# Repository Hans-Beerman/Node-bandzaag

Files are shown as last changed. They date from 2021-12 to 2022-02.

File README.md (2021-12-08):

**NodeStandard**

Node bandzaag is based on the standard node, and is used at the MakerSpace Leiden, to control the bandzaag. This repository has the following subdirs:

- **Drawings:**

Schematic of the wiring between the different modules used

- **KiCad\_files:**

The design of the PCB for the Node/Controller. De PCB in this design is not meant to be used for a real PCB. It is used as guideline for a handmade PCB

- **Photos:**

Some photos of the Node made.

- **PlatformIO\_Files:**

The source code for the Node and the display used. For the development of this software PlatformIO is used. PlatformIO is an Extension on Visual Studio Code.

Currently some of the directories are empty, because the node is not ready yet.

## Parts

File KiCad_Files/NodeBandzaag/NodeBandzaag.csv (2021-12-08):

Source: | /root/Projects/NodeBandzaag/KiCad_Files/NodeBandzaag/NodeBandzaag.sch
Date: | wo 08 dec 2021 19:24:39 CET
Tool: | Eeschema 5.1.12-84ad8e8a86~92~ubuntu20.04.1
Generator: | /usr/share/kicad/plugins/bom_csv_grouped_by_value.py
Component Count: | 36
Individual Components:
Item | Qty | Reference(s) | Value | LibPart | Footprint | Datasheet | Field4 | Field5
 |  | C1 | 10uF | Device:CP | Capacitor_THT:CP_Radial_D6.3mm_P2.50mm | ~
 |  | C8 | 100uF | Device:CP | Capacitor_THT:CP_Radial_D6.3mm_P2.50mm | ~
 |  | C9 | 2n2 | Device:C | Capacitor_THT:C_Disc_D5.1mm_W3.2mm_P5.00mm | ~
 |  | D1 | 1N4148 | Diode:1N4148 | Diode_THT:D_DO-35_SOD27_P7.62mm_Horizontal | https://assets.nexperia.com/documents/data-sheet/1N4148_1N4448.pdf
 |  | D2 | 1N4148 | Diode:1N4148 | Diode_THT:D_DO-35_SOD27_P7.62mm_Horizontal | https://assets.nexperia.com/documents/data-sheet/1N4148_1N4448.pdf
 |  | D3 | LED | Device:LED | LED_THT:LED_D3.0mm | ~
 |  | D5 | 1N4004 | Diode:1N4004 | Diode_THT:D_DO-41_SOD81_P10.16mm_Horizontal | http://www.vishay.com/docs/88503/1n4001.pdf
 |  | J1 | AC Current In | Connector:Screw_Terminal_01x02 | Connector_Phoenix_MSTB:PhoenixContact_MSTB_2,5_2-GF-5,08_1x02_P5.08mm_Horizontal_ThreadedFlange | ~
 |  | J2 | Current coil in | Connector:AudioJack3_SwitchTR | Jack_3.5mm_CUI_FEMPM_Horizontal | ~
 |  | J3 | AC Current loop | Connector:Screw_Terminal_01x02 | TerminalBlock_Phoenix:TerminalBlock_Phoenix_MKDS-1,5-2-5.08_1x02_P5.08mm_Horizontal | ~
 |  | J4 | EXT1 | Connector_Generic:Conn_01x10 | Connector_PinSocket_2.54mm:PinSocket_1x10_P2.54mm_Vertical | ~
 |  | J6 | RFIDReader | Connector:Screw_Terminal_01x04 | TerminalBlock_Phoenix:TerminalBlock_Phoenix_MPT-0,5-4-2.54_1x04_P2.54mm_Horizontal | ~
 |  | J7 | EXT2 | Connector_Generic:Conn_01x10 | Connector_PinSocket_2.54mm:PinSocket_1x10_P2.54mm_Vertical | ~
 |  | J8 | Force output Relay 1 on | Connector_Generic:Conn_01x02 | Connector_PinHeader_2.54mm:PinHeader_1x02_P2.54mm_Vertical | ~
 |  | J10 | Opto Coupler 1 in | Connector:Screw_Terminal_01x02 | Connector_Phoenix_MSTB:PhoenixContact_MSTB_2,5_2-GF-5,08_1x02_P5.08mm_Horizontal_ThreadedFlange | ~
 |  | J13 | Relay 1 Output | Connector:Screw_Terminal_01x03 | Connector_Phoenix_MSTB:PhoenixContact_MSTB_2,5_3-GF-5,08_1x03_P5.08mm_Horizontal_ThreadedFlange | ~
 |  | J29 | Current sensor select | Connector_Generic:Conn_01x03 | Connector_PinHeader_2.54mm:PinHeader_1x03_P2.54mm_Vertical | ~
 |  | JP1 | 230VAC-N | Jumper:SolderJumper_2_Open | Footprints:SolderJumper-2_P3mm_Open_RoundedPad | ~
 |  | JP4 | 230VAC-L | Jumper:SolderJumper_2_Open | Footprints:SolderJumper-2_P3mm_Open_RoundedPad | ~
 |  | K1 | SANYOU_SRD_Form_C | Relay:SANYOU_SRD_Form_C | Relay_THT:Relay_SPDT_SANYOU_SRD_Series_Form_C | http://www.sanyourelay.ca/public/products/pdf/SRD.pdf
 |  | L1 | TA12 | ZMCT118F:ZMCT118F | Footprints:TA12-100 | ~
 |  | OK1 | PC814 | PC814:PC814 | Package_DIP:DIP-4_W7.62mm |  | unknown | 9707662
 |  | Q1 | BC547 | Transistor_BJT:BC547 | Package_TO_SOT_THT:TO-92_Inline | http://www.fairchildsemi.com/ds/BC/BC547.pdf
 |  | Q6 | 2N3906 | Transistor_BJT:2N3906 | Package_TO_SOT_THT:TO-92_Inline | https://www.onsemi.com/pub/Collateral/2N3906-D.PDF
 |  | R1 | 33 | Device:R | Resistor_THT:R_Axial_DIN0207_L6.3mm_D2.5mm_P7.62mm_Horizontal | ~
 |  | R2 | 4k7 | Device:R | Resistor_THT:R_Axial_DIN0207_L6.3mm_D2.5mm_P7.62mm_Horizontal | ~
 |  | R3 | 2k2 | Device:R | Resistor_THT:R_Axial_DIN0207_L6.3mm_D2.5mm_P7.62mm_Horizontal | ~
 |  | R4 | 4k7 | Device:R | Resistor_THT:R_Axial_DIN0207_L6.3mm_D2.5mm_P7.62mm_Horizontal | ~
 |  | R5 | 22k | Device:R | Resistor_THT:R_Axial_DIN0207_L6.3mm_D2.5mm_P7.62mm_Horizontal | ~
 |  | R6 | 22k | Device:R | Resistor_THT:R_Axial_DIN0207_L6.3mm_D2.5mm_P7.62mm_Horizontal | ~
 |  | R9 | 1k | Device:R | Resistor_THT:R_Axial_DIN0207_L6.3mm_D2.5mm_P7.62mm_Horizontal | ~
 |  | R11 | 2k2 | Device:R | Resistor_THT:R_Axial_DIN0207_L6.3mm_D2.5mm_P7.62mm_Horizontal | ~
 |  | R13 | 220k | Device:R | Resistor_THT:R_Axial_DIN0516_L15.5mm_D5.0mm_P20.32mm_Horizontal | ~
 |  | R14 | 220k | Device:R | Resistor_THT:R_Axial_DIN0516_L15.5mm_D5.0mm_P20.32mm_Horizontal | ~
 |  | R30 | 1k | Device:R | Resistor_THT:R_Axial_DIN0207_L6.3mm_D2.5mm_P7.62mm_Horizontal | ~
 |  | U1 | MCP23017_SP | Interface_Expansion:MCP23017_SP | Package_DIP:DIP-28_W7.62mm | http://ww1.microchip.com/downloads/en/DeviceDoc/20001952C.pdf
Collated Components:
Item | Qty | Reference(s) | Value | LibPart | Footprint | Datasheet | Field4 | Field5
1 | 1 | C1 | 10uF | Device:CP | Capacitor_THT:CP_Radial_D6.3mm_P2.50mm | ~
2 | 1 | C8 | 100uF | Device:CP | Capacitor_THT:CP_Radial_D6.3mm_P2.50mm | ~
3 | 1 | C9 | 2n2 | Device:C | Capacitor_THT:C_Disc_D5.1mm_W3.2mm_P5.00mm | ~
4 | 2 | D1, D2 | 1N4148 | Diode:1N4148 | Diode_THT:D_DO-35_SOD27_P7.62mm_Horizontal | https://assets.nexperia.com/documents/data-sheet/1N4148_1N4448.pdf
5 | 1 | D3 | LED | Device:LED | LED_THT:LED_D3.0mm | ~
6 | 1 | D5 | 1N4004 | Diode:1N4004 | Diode_THT:D_DO-41_SOD81_P10.16mm_Horizontal | http://www.vishay.com/docs/88503/1n4001.pdf
7 | 1 | J1 | AC Current In | Connector:Screw_Terminal_01x02 | Connector_Phoenix_MSTB:PhoenixContact_MSTB_2,5_2-GF-5,08_1x02_P5.08mm_Horizontal_ThreadedFlange | ~
8 | 1 | J2 | Current coil in | Connector:AudioJack3_SwitchTR | Jack_3.5mm_CUI_FEMPM_Horizontal | ~
9 | 1 | J3 | AC Current loop | Connector:Screw_Terminal_01x02 | TerminalBlock_Phoenix:TerminalBlock_Phoenix_MKDS-1,5-2-5.08_1x02_P5.08mm_Horizontal | ~
10 | 1 | J4 | EXT1 | Connector_Generic:Conn_01x10 | Connector_PinSocket_2.54mm:PinSocket_1x10_P2.54mm_Vertical | ~
11 | 1 | J6 | RFIDReader | Connector:Screw_Terminal_01x04 | TerminalBlock_Phoenix:TerminalBlock_Phoenix_MPT-0,5-4-2.54_1x04_P2.54mm_Horizontal | ~
12 | 1 | J7 | EXT2 | Connector_Generic:Conn_01x10 | Connector_PinSocket_2.54mm:PinSocket_1x10_P2.54mm_Vertical | ~
13 | 1 | J8 | Force output Relay 1 on | Connector_Generic:Conn_01x02 | Connector_PinHeader_2.54mm:PinHeader_1x02_P2.54mm_Vertical | ~
14 | 1 | J10 | Opto Coupler 1 in | Connector:Screw_Terminal_01x02 | Connector_Phoenix_MSTB:PhoenixContact_MSTB_2,5_2-GF-5,08_1x02_P5.08mm_Horizontal_ThreadedFlange | ~
15 | 1 | J13 | Relay 1 Output | Connector:Screw_Terminal_01x03 | Connector_Phoenix_MSTB:PhoenixContact_MSTB_2,5_3-GF-5,08_1x03_P5.08mm_Horizontal_ThreadedFlange | ~
16 | 1 | J29 | Current sensor select | Connector_Generic:Conn_01x03 | Connector_PinHeader_2.54mm:PinHeader_1x03_P2.54mm_Vertical | ~
17 | 1 | JP1 | 230VAC-N | Jumper:SolderJumper_2_Open | Footprints:SolderJumper-2_P3mm_Open_RoundedPad | ~
18 | 1 | JP4 | 230VAC-L | Jumper:SolderJumper_2_Open | Footprints:SolderJumper-2_P3mm_Open_RoundedPad | ~
19 | 1 | K1 | SANYOU_SRD_Form_C | Relay:SANYOU_SRD_Form_C | Relay_THT:Relay_SPDT_SANYOU_SRD_Series_Form_C | http://www.sanyourelay.ca/public/products/pdf/SRD.pdf
20 | 1 | L1 | TA12 | ZMCT118F:ZMCT118F | Footprints:TA12-100 | ~
21 | 1 | OK1 | PC814 | PC814:PC814 | Package_DIP:DIP-4_W7.62mm |  | unknown | 9707662
22 | 1 | Q1 | BC547 | Transistor_BJT:BC547 | Package_TO_SOT_THT:TO-92_Inline | http://www.fairchildsemi.com/ds/BC/BC547.pdf
23 | 1 | Q6 | 2N3906 | Transistor_BJT:2N3906 | Package_TO_SOT_THT:TO-92_Inline | https://www.onsemi.com/pub/Collateral/2N3906-D.PDF
24 | 1 | R1 | 33 | Device:R | Resistor_THT:R_Axial_DIN0207_L6.3mm_D2.5mm_P7.62mm_Horizontal | ~
25 | 2 | R2, R4 | 4k7 | Device:R | Resistor_THT:R_Axial_DIN0207_L6.3mm_D2.5mm_P7.62mm_Horizontal | ~
26 | 2 | R3, R11 | 2k2 | Device:R | Resistor_THT:R_Axial_DIN0207_L6.3mm_D2.5mm_P7.62mm_Horizontal | ~
27 | 2 | R5, R6 | 22k | Device:R | Resistor_THT:R_Axial_DIN0207_L6.3mm_D2.5mm_P7.62mm_Horizontal | ~
28 | 2 | R9, R30 | 1k | Device:R | Resistor_THT:R_Axial_DIN0207_L6.3mm_D2.5mm_P7.62mm_Horizontal | ~
29 | 2 | R13, R14 | 220k | Device:R | Resistor_THT:R_Axial_DIN0516_L15.5mm_D5.0mm_P20.32mm_Horizontal | ~
30 | 1 | U1 | MCP23017_SP | Interface_Expansion:MCP23017_SP | Package_DIP:DIP-28_W7.62mm | http://ww1.microchip.com/downloads/en/DeviceDoc/20001952C.pdf

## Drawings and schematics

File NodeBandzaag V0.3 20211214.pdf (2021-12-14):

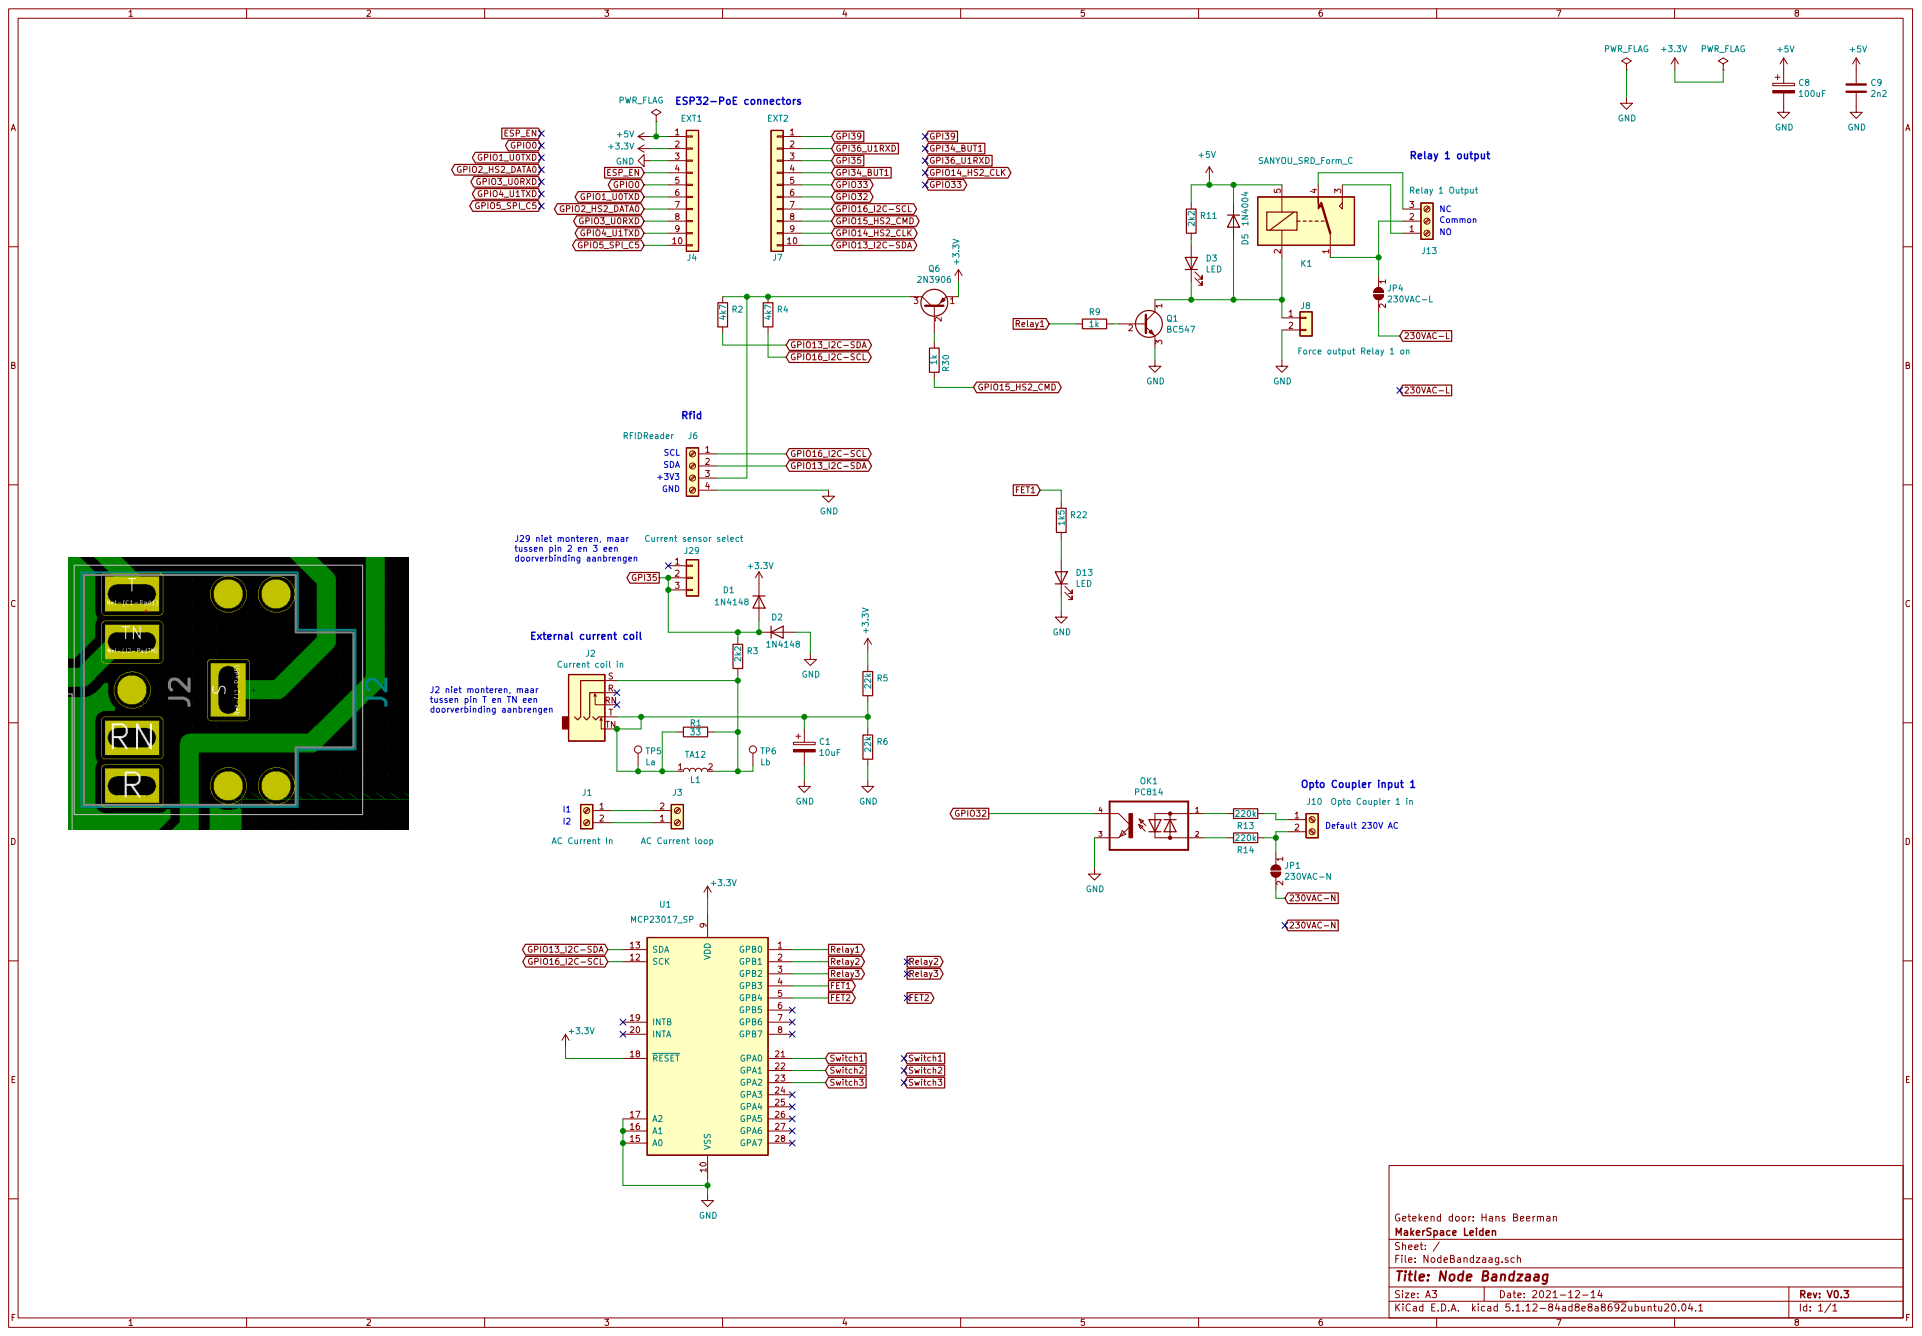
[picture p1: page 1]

Common Default 230V AC
NO Opto Coupler input 1

J29 niet monteren, maar
tussen pin 2 en 3 een
doorverbinding aanbrengen

J2 niet monteren, maar
tussen pin T en TN een

File: NodeBandzaag.sch Sheet: / MakerSpace Leiden Getekend door: Hans Beerman

Id: 1/1 Title: Node Bandzaag

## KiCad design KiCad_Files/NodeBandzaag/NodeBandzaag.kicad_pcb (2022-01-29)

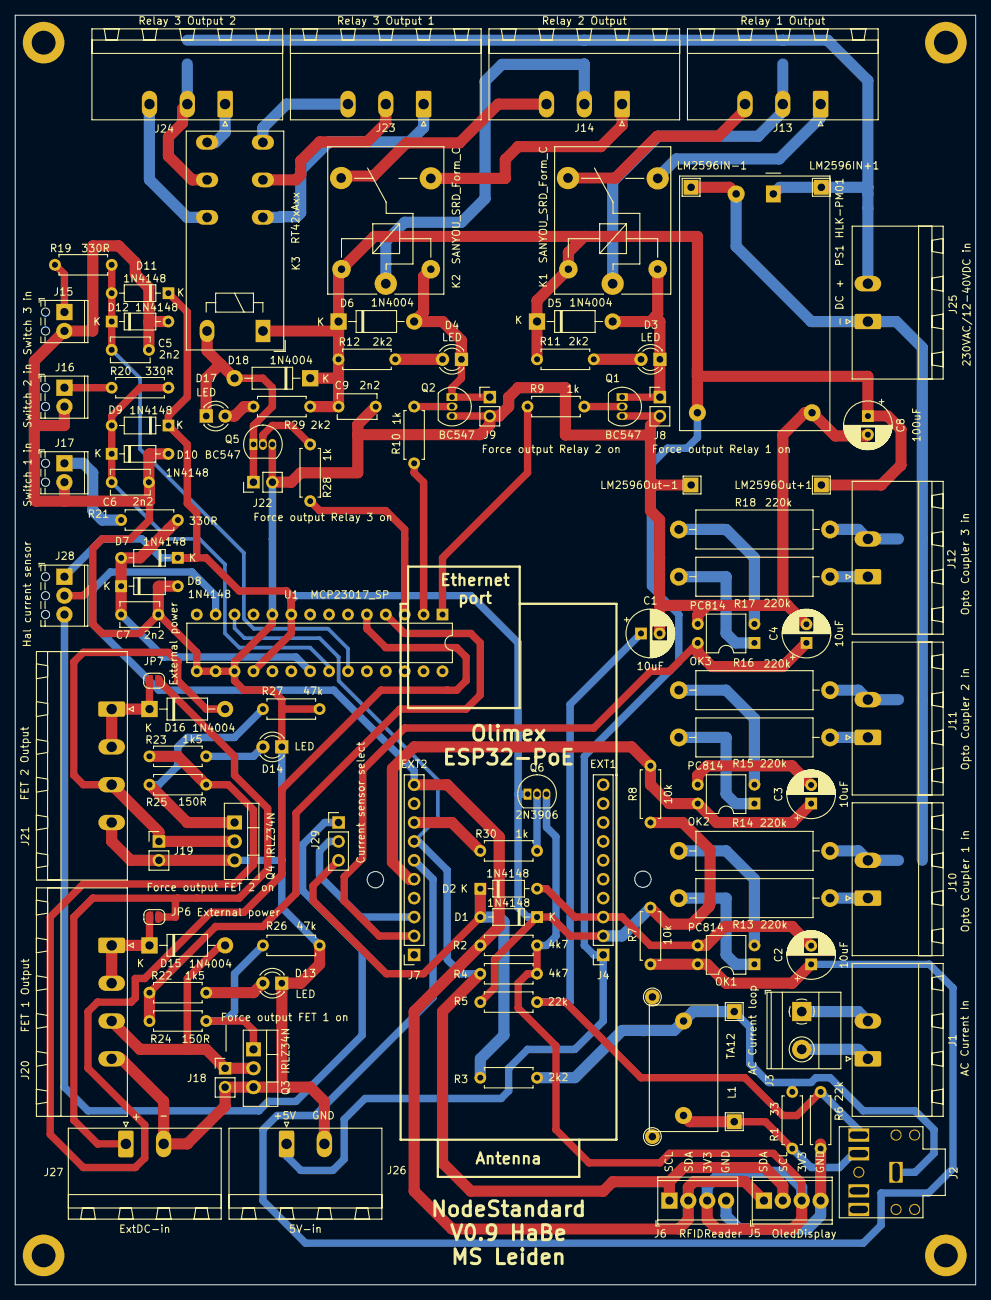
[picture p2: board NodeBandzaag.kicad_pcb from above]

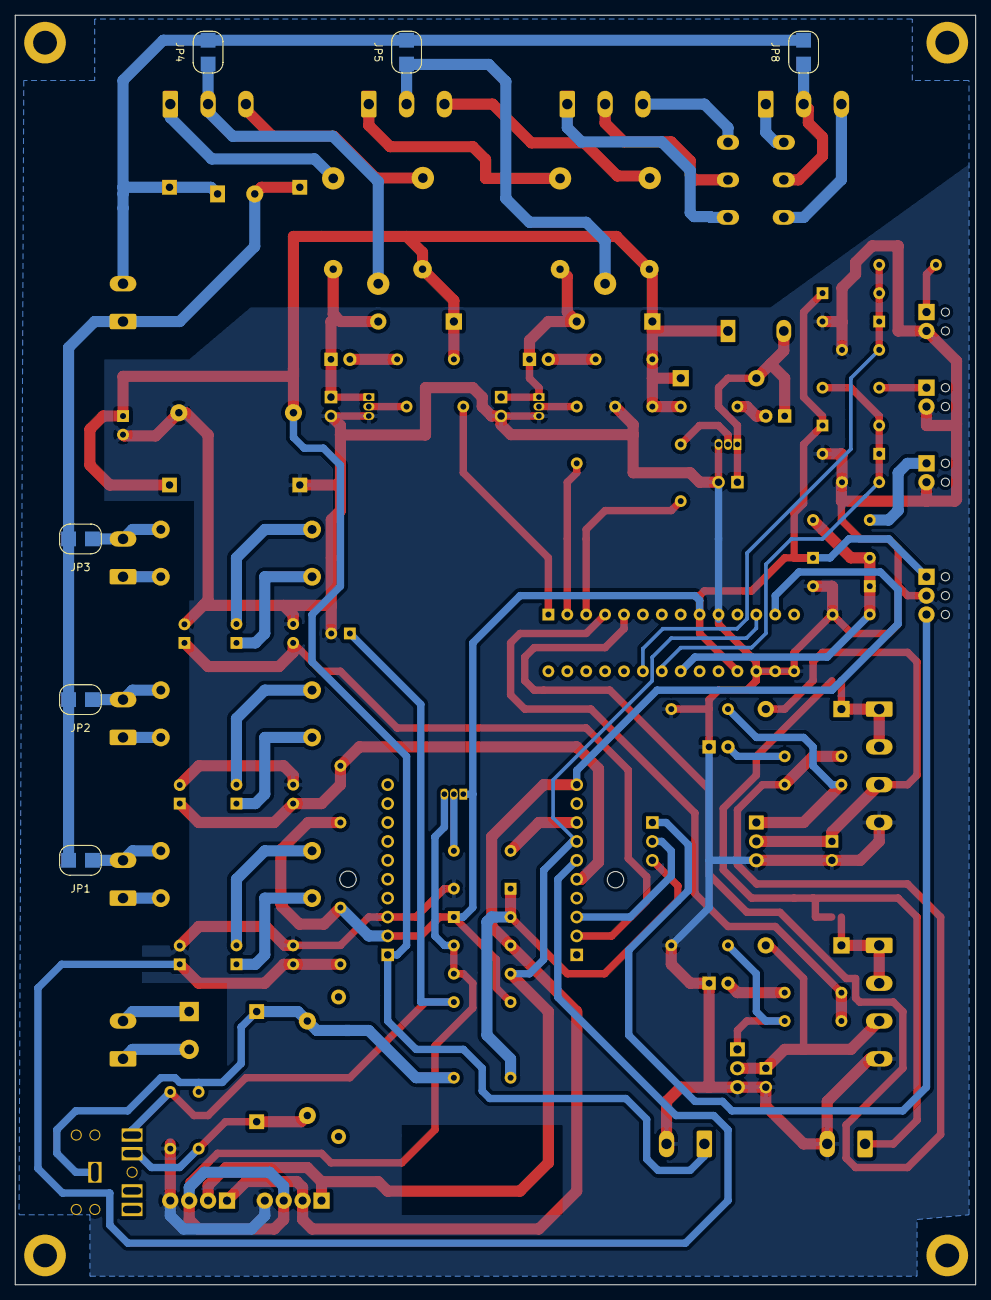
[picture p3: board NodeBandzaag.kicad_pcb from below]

Board: 2 copper layers, 129.0 x 170.6 mm, 115 parts (6 on the bottom side), 74 nets.

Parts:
C1, C2, C3, C4: 10uF; CP_Radial_D6.3mm_P2.50mm
C5, C6, C7, C9: 2n2; C_Disc_D5.1mm_W3.2mm_P5.00mm
C8: 100uF; CP_Radial_D6.3mm_P2.50mm
D1, D2, D7, D8, D9, D10, D11, D12: 1N4148; D_DO-35_SOD27_P7.62mm_Horizontal
D3, D4, D13, D14, D17: LED; LED_D3.0mm
D5, D6, D15, D16, D18: 1N4004; D_DO-41_SOD81_P10.16mm_Horizontal
J1: AC Current In; PhoenixContact_MSTB_2,5_2-GF-5,08_1x02_P5.08mm_Horizontal_T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
J2: Current coil in; Jack_3.5mm_CUI_FEMPM_Horizontal
J3: AC Current loop; TerminalBlock_Phoenix_MKDS-1,5-2-5.08_1x02_P5.08mm_Horizont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
J4: EXT1; PinSocket_1x10_P2.54mm_Vertical
J5: OledDisplay; TerminalBlock_Phoenix_MPT-0,5-4-2.54_1x04_P2.54mm_Horizontal
J6: RFIDReader; TerminalBlock_Phoenix_MPT-0,5-4-2.54_1x04_P2.54mm_Horizontal
J7: EXT2; PinSocket_1x10_P2.54mm_Vertical
J8: Force output Relay 1 on; PinHeader_1x02_P2.54mm_Vertical
J9: Force output Relay 2 on; PinHeader_1x02_P2.54mm_Vertical
J10: Opto Coupler 1 in; PhoenixContact_MSTB_2,5_2-GF-5,08_1x02_P5.08mm_Horizontal_T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
J11: Opto Coupler 2 in; PhoenixContact_MSTB_2,5_2-GF-5,08_1x02_P5.08mm_Horizontal_T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
J12: Opto Coupler 3 in; PhoenixContact_MSTB_2,5_2-GF-5,08_1x02_P5.08mm_Horizontal_T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
J13: Relay 1 Output; PhoenixContact_MSTB_2,5_3-GF-5,08_1x03_P5.08mm_Horizontal_T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
J14: Relay 2 Output; PhoenixContact_MSTB_2,5_3-GF-5,08_1x03_P5.08mm_Horizontal_T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
J15: Switch 3 in; TerminalBlock_Phoenix_MPT-0,5-2-2.54_1x02_P2.54mm_Horizontal
J16: Switch 2 in; TerminalBlock_Phoenix_MPT-0,5-2-2.54_1x02_P2.54mm_Horizontal
J17: Switch 1 in; TerminalBlock_Phoenix_MPT-0,5-2-2.54_1x02_P2.54mm_Horizontal
J18: Force output FET 1 on; PinHeader_1x02_P2.54mm_Vertical
J19: Force output FET 2 on; PinHeader_1x02_P2.54mm_Vertical
J20: FET 1 Output; PhoenixContact_MSTB_2,5_4-GF-5,08_1x04_P5.08mm_Horizontal_T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
J21: FET 2 Output; PhoenixContact_MSTB_2,5_4-GF-5,08_1x04_P5.08mm_Horizontal_T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
J22: Force output Relay 3 on; PinHeader_1x02_P2.54mm_Vertical
J23: Relay 3 Output 1; PhoenixContact_MSTB_2,5_3-GF-5,08_1x03_P5.08mm_Horizontal_T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
J24: Relay 3 Output 2; PhoenixContact_MSTB_2,5_3-GF-5,08_1x03_P5.08mm_Horizontal_T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
J25: 230VAC/12-40VDC in; PhoenixContact_MSTB_2,5_2-GF-5,08_1x02_P5.08mm_Horizontal_T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
J26: 5V-in; PhoenixContact_MSTB_2,5_2-GF-5,08_1x02_P5.08mm_Horizontal_T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
J27: ExtDC-in; PhoenixContact_MSTB_2,5_2-GF-5,08_1x02_P5.08mm_Horizontal_T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
J28: Hal current sensor; TerminalBlock_Phoenix_MPT-0,5-3-2.54_1x03_P2.54mm_Horizontal
J29: Current sensor select; PinHeader_1x03_P2.54mm_Vertical
JP1, JP2, JP3: 230VAC-N; SolderJumper-2_P3mm_Open_RoundedPad
JP4, JP5, JP8: 230VAC-L; SolderJumper-2_P3mm_Open_RoundedPad
JP6, JP7: External power; SolderJumper-2_P1.3mm_Open_RoundedPad1.0x1.5mm
K1, K2: SANYOU_SRD_Form_C; Relay_SPDT_SANYOU_SRD_Series_Form_C
K3: RT42xAxx; Relay_DPDT_Schrack-RT2-FormC_RM5mm
L1: TA12; TA12-100
LM2596IN+1: IN+; TestPoint_THTPad_2.0x2.0mm_Drill1.0mm
LM2596IN-1: IN-; TestPoint_THTPad_2.0x2.0mm_Drill1.0mm
LM2596Out+1: Out+; TestPoint_THTPad_2.0x2.0mm_Drill1.0mm
LM2596Out-1: OUT-; TestPoint_THTPad_2.0x2.0mm_Drill1.0mm
OK1, OK2, OK3: PC814; DIP-4_W7.62mm
PS1: HLK-PM01; Converter_ACDC_HiLink_HLK-PMxx
Q1, Q2, Q5: BC547; TO-92_Inline
Q3, Q4: IRLZ34N; TO-220-3_Vertical
Q6: 2N3906; TO-92_Inline
R1: 33; R_Axial_DIN0207_L6.3mm_D2.5mm_P7.62mm_Horizontal
R2, R4: 4k7; R_Axial_DIN0207_L6.3mm_D2.5mm_P7.62mm_Horizontal
R3, R11, R12, R29: 2k2; R_Axial_DIN0207_L6.3mm_D2.5mm_P7.62mm_Horizontal
R5, R6: 22k; R_Axial_DIN0207_L6.3mm_D2.5mm_P7.62mm_Horizontal
R7, R8: 10k; R_Axial_DIN0207_L6.3mm_D2.5mm_P7.62mm_Horizontal
R9, R10, R28, R30: 1k; R_Axial_DIN0207_L6.3mm_D2.5mm_P7.62mm_Horizontal
R13, R14, R15, R16, R17, R18: 220k; R_Axial_DIN0516_L15.5mm_D5.0mm_P20.32mm_Horizontal
R19, R20, R21: 330R; R_Axial_DIN0207_L6.3mm_D2.5mm_P7.62mm_Horizontal
R22, R23: 1k5; R_Axial_DIN0207_L6.3mm_D2.5mm_P7.62mm_Horizontal
R24, R25: 150R; R_Axial_DIN0207_L6.3mm_D2.5mm_P7.62mm_Horizontal
R26, R27: 47k; R_Axial_DIN0207_L6.3mm_D2.5mm_P7.62mm_Horizontal
TP5: La; TestPoint_THTPad_2.0x2.0mm_Drill1.0mm
TP6: Lb; TestPoint_THTPad_2.0x2.0mm_Drill1.0mm
U1: MCP23017_SP; DIP-28_W7.62mm

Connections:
230VAC-L: J25.2, JP4.2, JP5.2, JP8.2, LM2596IN+1.1, PS1.1
230VAC-N: J25.1, JP1.2, JP2.2, JP3.2, LM2596IN-1.1, PS1.2
+3V3: D1.1, D7.1, D9.1, D11.1, J4.2, J28.1, Q6.1, R5.1, R7.1, R8.1, U1.9, U1.18
+5V: C8.1, C9.1, D5.1, D6.1, D18.1, J4.1, J26.1, K1.5, K2.5, K3.A1, LM2596Out+1.1, PS1.4, R11.1, R12.1, R29.1
ExternalDCPower: J27.1, JP6.1, JP7.1
FET1: R22.1, R24.2, U1.4
FET2: R23.1, R25.2, U1.5
GND: C1.2, C2.2, C3.2, C4.2, C5.2, C6.2, C7.2, C8.2, C9.2, D2.2, D8.2, D10.2, D12.2, D13.1, D14.1, J4.3, J5.4, J6.4, J8.2, J9.2, J15.2, J16.2, J17.2, J18.2, J19.2, J20.4, J21.4, J22.2, J26.2, J27.2, J28.2, LM2596Out-1.1, OK1.3, OK2.3, OK3.3, PS1.3, Q1.3, Q2.3, Q3.3, Q4.3, Q5.3, R6.2, R26.2, R27.2, U1.10, U1.15, U1.16, U1.17
GPI35: J7.3, J29.2
GPI36_U1RXD: C4.1, J7.2, OK3.4
GPIO13_I2C-SDA: J5.1, J6.2, J7.10, R2.2, U1.13
GPIO15_HS2_CMD: J7.8, R30.1
GPIO16_I2C-SCL: J5.2, J6.1, J7.7, R4.2, U1.12
GPIO32: C2.1, J7.6, OK1.4, R7.2
GPIO33: C3.1, J7.5, OK2.4, R8.2
unnamed: C1.1, J2.T, R5.2, R6.1
unnamed: D1.2, D2.1, J29.3, R3.1
unnamed: D3.1, D5.2, J8.1, K1.2, Q1.1
unnamed: D3.2, R11.2
unnamed: D4.1, D6.2, J9.1, K2.2, Q2.1
unnamed: D4.2, R12.2
unnamed: D13.2, R22.2
unnamed: D14.2, R23.2
unnamed: D15.1, J20.1, J20.2, JP6.2
unnamed: D15.2, J18.1, J20.3, Q3.2
unnamed: D16.1, J21.1, J21.2, JP7.2
unnamed: D16.2, J19.1, J21.3, Q4.2
unnamed: D17.1, D18.2, J22.1, K3.A2, Q5.1
unnamed: D17.2, R29.2
unnamed: J1.1, J3.2
unnamed: J1.2, J3.1
unnamed: J2.S, L1.2, R1.1, R3.2, TP6.1
unnamed: J2.TN, L1.1, R1.2, TP5.1
unnamed: J5.3, J6.3, Q6.3, R2.1, R4.1
unnamed: J10.1, R13.1
unnamed: J10.2, JP1.1, R14.1
unnamed: J11.1, R15.1
unnamed: J11.2, JP2.1, R16.1
unnamed: J12.1, R17.1
unnamed: J12.2, JP3.1, R18.1
unnamed: J13.1, K1.3
unnamed: J13.2, JP4.1, K1.1
unnamed: J13.3, K1.4
unnamed: J14.1, K2.3
unnamed: J14.2, JP5.1, K2.1
unnamed: J14.3, K2.4
unnamed: J15.1, R19.1
unnamed: J16.1, R20.1
unnamed: J17.1, R21.1
unnamed: J23.1, K3.12
unnamed: J23.2, K3.11
unnamed: J23.3, K3.14
unnamed: J24.1, K3.24
unnamed: J24.2, JP8.1, K3.21
unnamed: J24.3, K3.22
unnamed: J28.3, J29.1
unnamed: OK1.1, R13.2
unnamed: OK1.2, R14.2
unnamed: OK2.1, R15.2
unnamed: OK2.2, R16.2
unnamed: OK3.1, R17.2
unnamed: OK3.2, R18.2
unnamed: Q1.2, R9.1
unnamed: Q2.2, R10.1
unnamed: Q3.1, R24.1, R26.1
unnamed: Q4.1, R25.1, R27.1
unnamed: Q5.2, R28.1
unnamed: Q6.2, R30.2
Relay1: R9.2, U1.1
Relay2: R10.2, U1.2
Relay3: R28.2, U1.3
Switch1: C7.1, D7.2, D8.1, R21.2, U1.21
Switch2: C6.1, D9.2, D10.1, R20.2, U1.22
Switch3: C5.1, D11.2, D12.1, R19.2, U1.23

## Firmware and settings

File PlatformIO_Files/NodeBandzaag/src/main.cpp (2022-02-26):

/*
   Copyright 2015-2018 Dirk-Willem van Gulik <dirkx@webweaving.org>
   Copyright 2020-2021 Hans Beerman <hans.beerman@xs4all.nl>
                       Stichting Makerspace Leiden, the Netherlands.

   Licensed under the Apache License, Version 2.0 (the "License");
   you may not use this file except in compliance with the License.
   You may obtain a copy of the License at

       http://www.apache.org/licenses/LICENSE-2.0

   Unless required by applicable law or agreed to in writing, software
   distributed under the License is distributed on an "AS IS" BASIS,
   WITHOUT WARRANTIES OR CONDITIONS OF ANY KIND, either express or implied.
   See the License for the specific language governing permissions and
   limitations under the License.
*/

#ifndef ESP32
#error "The Node lintzaag uses an ESP32 based board (Olimex ESP32-PoE)!"
#endif

// An Olimex ESP32-PoE is used (default is POESP board (Aart board))
#define ESP32_PoE


// for debugging
// see DEBUGIT flag in platformio.ini

// i2C params
// Defined in platformio.ini:
// RFID_SDA_PIN=13
// RFID_SCL_PIN=16

#include <Arduino.h>
#include <PowerNodeV11.h>
#include <ACNode.h>
#include <RFID.h>   // NFC version
#include <SIG2.h>
#include <Cache.h>
#include <OptoDebounce.h>
#include <ButtonDebounce.h>
#include <EEPROM.h>
#include <WiFiUdp.h>
#include <NTP.h> // install NTP by Stefan Staub
#include <CurrentTransformerWithCallbacks.h>

//
// information about NTP.h, see: https://platformio.org/lib/show/5438/NTP
//

#include "MCP23017IO.h"
#include ".passwd.h"

/* If using WiFi instead of a fixed ethernet connection, and/or OTA:

Change .passwd.h in the /include directoy containing the following information

#pragma once

#define WIFI_NETWORK "YOUR_SSID"
#define WIFI_PASSWD "YOUR_PASSWD"

#define OTA_PASSWD "YOUR_OTA_PASSWD"
// This OTA_PASSWD must be the same as the one in platformio.ini
*/

// software version
#define SOFTWARE_VERSION "  V1.0.5.0 "

#define MACHINE "lintzaag"

// See https://mailman.makerspaceleiden.nl/mailman/private/deelnemers/2019-February/019837.html

// Introduced by alex - 2020-01-8

// Clear EEProm + Cache button
// Press BUT1 on Olimex ESP32 PoE module before (re)boot of node
// keep BUT1 pressed for at least 5 s
// After the release of BUT1 node will restart with empty EEProm and empty cache
#define CLEAR_EEPROM_AND_CACHE_BUTTON           (34)
#define CLEAR_EEPROM_AND_CACHE_BUTTON_PRESSED   (LOW)
#define MAX_WAIT_TIME_BUTTON_PRESSED            (4000)  // in ms

#define MAX_WAIT_FOR_CARD_TIME                  (20) // in s = 20 seconds

// for normal operation
#define MAX_ACTIVE_TIME                         (120) // in minutes = 2 hour
// for test
// #define MAX_ACTIVE_TIME                         (1) // in minutes = 1 minute
// for normal operation
// #define MAX_IDLE_TIME                           (35 * 60 * 1000) // auto power off after 35 minutes of no use.
#define MAX_IDLE_TIME                           (100 * 1000) // auto power off after 100 s of no use.
// for test
// #define MAX_IDLE_TIME                           (1 * 60 * 1000) // auto power off after 1 minute of no use.

#define SWITCH_POWER_OFF_WAITTIME               (3000) // in ms

#define CHECK_NFC_READER_AVAILABLE_TIME_WINDOW  (10000) // in ms  
#define GPIOPORT_I2C_RECOVER_SWITCH             (15)       

#define OPTO_COUPLER_INPUT1                     (32)
#define OPTO_COUPLER_INPUT2                     (33)
#define OPTO_COUPLER_INPUT3                     (36)

#define CURRENT_SAMPLES_PER_SEC                 (500) // one sample each 2 ms
#define CURRENT_THRESHOLD                       (0.07)  // Irms ~ 4A, with current transformer 1:1000 and resistor of 36 ohm

#define BLINK_NOT_CONNECTED                     (1000)	// blink on/of every 1000 ms
#define BLINK_ERROR                             (300) // blink on/of every 300 ms
#define BLINK_CHECKING_RFIDCARD                 (600) // blink on/of every 600 ms

CurrentTransformerWithCallbacks currentSensor = CurrentTransformerWithCallbacks(CURRENT_GPIO, CURRENT_SAMPLES_PER_SEC);

// 230VAC optocoupler
OptoDebounce opto1(OPTO_COUPLER_INPUT1); // wired to the 230VAC of the welding equipment, to detect if it is switched on or not

bool opto1IsOn = false;
bool previousOpto1IsOn = false;
bool opto1Error = false;
bool powerWhileSwitchedOffError = false;
bool switchPowerOff = false;

#ifdef WIFI_NETWORK
ACNode node = ACNode(MACHINE, WIFI_NETWORK, WIFI_PASSWD);
#else
ACNode node = ACNode(MACHINE);
#endif

#define USE_CACHE_FOR_TAGS true
#define USE_NFC_RFID_CARD true

// NTP update window
#define NTP_UPDATE_WINDOW (60000) // in ms

RFID reader = RFID(USE_CACHE_FOR_TAGS, USE_NFC_RFID_CARD); // use tags are stored in cache, to allow access in case the MQTT server is down; also use NFC RFID card

MqttLogStream mqttlogStream = MqttLogStream();
TelnetSerialStream telnetSerialStream = TelnetSerialStream();

#ifdef OTA_PASSWD
OTA ota = OTA(OTA_PASSWD);
#endif

WiFiUDP wifiUDP;
NTP ntp(wifiUDP);

char ntpBootDateTimeStr[64];
unsigned long NTPUpdatedTime = 0;
int previousHour = -1;

char ntpCurrentDateTimeStr[64];
int currentHour;
int currentMinutes;
int currentSecs;
int currentDay;
int currentMonth;
int currentYear;

// LED aartLed = LED(SYSTEM_LED);    // defaults to the aartLed - otherwise specify a GPIO.

typedef enum {
  BOOTING,                  // starting up
  OUTOFORDER,               // device not functional.
  REBOOT,                   // forcefull reboot
  TRANSIENTERROR,           // hopefully goes away level error
  NOCONN,                   // sort of fairly hopless (though we can cache RFIDs!)
  NOTACTIVE,                // waiting for card.
  CHECKINGCARD,
  CLEARSTATUS,
  APPROVED,
  REJECTCARD,
  REJECTED,
  POWERED,
  ACTIVE,                   // running
} machinestates_t;


#define NEVER (0)

struct {
  const char * label;                   // name of this state
  LED::led_state_t ledState;            // flashing pattern for the aartLED. Zie ook https://wiki.makerspaceleiden.nl/mediawiki/index.php/Powernode_1.1.
  time_t maxTimeInMilliSeconds;         // how long we can stay in this state before we timeout.
  machinestates_t failStateOnTimeout;   // what state we transition to on timeout.
  unsigned long timeInState;
  unsigned long timeoutTransitions;
  unsigned long autoReportCycle;
} state[ACTIVE + 1] =
{
  { "Booting",                           LED::LED_ERROR,                      120 * 1000, REBOOT,                       0 },
  { "Module out of order",               LED::LED_ERROR,                      120 * 1000, REBOOT,                       5 * 60 * 1000 },
  { "Rebooting",                         LED::LED_ERROR,                      120 * 1000, REBOOT,                       0 },
  { "Transient Error",                   LED::LED_ERROR,                        5 * 1000, NOTACTIVE,                    5 * 60 * 1000 },
  { "No network",                        LED::LED_FLASH,                           NEVER, NOCONN,                       0 },
  { "Not active",                        LED::LED_IDLE,                            NEVER, NOTACTIVE,                    0 },
  { "Checking card",                     LED::LED_PENDING,                      7 * 1000, REJECTCARD,                   0 },
  { "Clear status",                      LED::LED_PENDING,                         NEVER, NOTACTIVE,                    0 },
  { "Approved card",                     LED::LED_PENDING, MAX_WAIT_FOR_CARD_TIME * 1000, CLEARSTATUS,                  0 },
  { "Reject card",                       LED::LED_ERROR,                        5 * 1000, REJECTED,                     0 },
  { "Rejected",                          LED::LED_ERROR,                        7 * 1000, CLEARSTATUS,                  0 },
  { "Powered - but idle",                LED::LED_ON,                              NEVER, NOTACTIVE,                    0 },
  { "Active (running)",                  LED::LED_ON,        MAX_ACTIVE_TIME * 60 * 1000, CLEARSTATUS,                  0 },
};

unsigned long laststatechange = 0, lastReport = 0;
static machinestates_t laststate = OUTOFORDER;
machinestates_t machinestate = BOOTING;

unsigned long switchPowerOffTime = 0;

// to handle onconnect only once (only after reboot)
static bool firstOnConnectTime = true;

char reportStr[128];

unsigned long approvedCards = 0;
unsigned long rejectedCards = 0;

// For storing the local IP address of the node
IPAddress theLocalIPAddress;

unsigned long lastCheckNFCReaderTime = 0;

bool nodeWasConnected = false;

void checkClearEEPromAndCacheButtonPressed(void) {
  unsigned long ButtonPressedTime;
  unsigned long currentSecs;
  unsigned long prevSecs;
  bool firstTime = true;

  // check CLEAR_EEPROM_AND_CACHE_BUTTON pressed
  pinMode(CLEAR_EEPROM_AND_CACHE_BUTTON, INPUT);
  // check if button is pressed for at least 3 s
  Log.println("Checking if the button is pressed for clearing EEProm and cache");
  ButtonPressedTime = millis();  
  prevSecs = MAX_WAIT_TIME_BUTTON_PRESSED / 1000;
  Log.print(prevSecs);
  Log.print(" s");
  while (digitalRead(CLEAR_EEPROM_AND_CACHE_BUTTON) == CLEAR_EEPROM_AND_CACHE_BUTTON_PRESSED) {
    if ((millis() - ButtonPressedTime) >= MAX_WAIT_TIME_BUTTON_PRESSED) {
      if (firstTime == true) {
        Log.print("\rPlease release button");
        firstTime = false;
      }
    } else {
      currentSecs = (MAX_WAIT_TIME_BUTTON_PRESSED - millis()) / 1000;
      if ((currentSecs != prevSecs) && (currentSecs >= 0)) {
        Log.print("\r");
        Log.print(currentSecs);
        Log.print(" s");
        prevSecs = currentSecs;
      }
    }
  }
  if (millis() - ButtonPressedTime >= MAX_WAIT_TIME_BUTTON_PRESSED) {
    Log.print("\rButton for clearing EEProm and cache was pressed for more than ");
    Log.print(MAX_WAIT_TIME_BUTTON_PRESSED / 1000);
    Log.println(" s, EEProm and Cache will be cleared!");
    // Clear EEPROM
    EEPROM.begin(1024);
    wipe_eeprom();
    Log.println("EEProm cleared!");
    // Clear cache
    prepareCache(true);
    Log.println("Cache cleared!");
    // wait until button is released, than reboot
    while (digitalRead(CLEAR_EEPROM_AND_CACHE_BUTTON) == CLEAR_EEPROM_AND_CACHE_BUTTON_PRESSED) {
    // do nothing here
    }
    Log.println("Node will be restarted");
    // restart node
    ESP.restart();
  } else {
    Log.println("\rButton was not (or not long enough) pressed to clear EEProm and cache");
  }
}

void setup_GPIO() {
  // for recovery switch I2C
  pinMode(GPIOPORT_I2C_RECOVER_SWITCH, OUTPUT);
  digitalWrite(GPIOPORT_I2C_RECOVER_SWITCH, 0);
}

#define CONNECTION_ERROR_INTERVAL_TIME        (1000)
#define CONNECTION_ERROR_TIME                 (100)

bool connectionErrorIsActive = false;
unsigned long connectionErrorTime = 0;

void resetNFCReader() {
  if (USE_NFC_RFID_CARD) {
    pinMode(RFID_SCL_PIN, OUTPUT);
    digitalWrite(RFID_SCL_PIN, 0);
    pinMode(RFID_SDA_PIN, OUTPUT);
    digitalWrite(RFID_SDA_PIN, 0);
    digitalWrite(GPIOPORT_I2C_RECOVER_SWITCH, 1);
    delay(500);
    digitalWrite(GPIOPORT_I2C_RECOVER_SWITCH, 0);
    reader.begin();
  }
}

void checkNFCReaderAvailable(bool onlyShowError) {
  if (USE_NFC_RFID_CARD) {
    if (!reader.CheckPN53xBoardAvailable()) {
      // Error in communuication with RFID reader, try resetting communication
      Serial.println("Error in communication with RFID reader. Resetting communication\r");
      pinMode(RFID_SCL_PIN, OUTPUT);
      digitalWrite(RFID_SCL_PIN, 0);
      pinMode(RFID_SDA_PIN, OUTPUT);
      digitalWrite(RFID_SDA_PIN, 0);
      digitalWrite(GPIOPORT_I2C_RECOVER_SWITCH, 1);
      delay(500);
      digitalWrite(GPIOPORT_I2C_RECOVER_SWITCH, 0);
      reader.begin();
    } else {
      // No error
      if (!onlyShowError) {
        Serial.println("Reader is available!\r");
      }
    }
  }
}

void getCurrentNTPDateTime() {
  currentHour = ntp.hours();
  currentMinutes = ntp.minutes();
  currentSecs = ntp.seconds();
  currentDay = ntp.day();
  currentMonth = ntp.month();
  currentYear = ntp.year();
  snprintf(ntpCurrentDateTimeStr, sizeof(ntpCurrentDateTimeStr), "%4d-%02d-%02d %02d:%02d:%02d", currentYear, currentMonth, currentDay, currentHour, currentMinutes, currentSecs);
}

void initNTP(void) {
  ntp.ruleDST("CEST", Last, Sun, Mar, 2, 120); // last sunday in march 2:00, timezone +120min (+1 GMT + 1h summertime offset)
  ntp.ruleSTD("CET", Last, Sun, Oct, 3, 60); // last sunday in october 3:00, timezone +60min (+1 GMT)
  ntp.begin();
  ntp.update();

  getCurrentNTPDateTime();

  snprintf(ntpBootDateTimeStr, sizeof(ntpBootDateTimeStr), "%s", ntpCurrentDateTimeStr);
}

void setup() {
  Serial.begin(115200);
  Serial.println("\n\n\n");
  Serial.println("Booted: " __FILE__ " " __DATE__ " " __TIME__ );
  
  setup_GPIO();
  
  setup_MCP23017();

  relay1Off();

  checkClearEEPromAndCacheButtonPressed();

  node.set_mqtt_prefix("ac");
  node.set_master("master");

  node.onConnect([]() {
    Log.println("Connected");
    if (firstOnConnectTime == true) {
      firstOnConnectTime = false;
      machinestate = NOTACTIVE;
      if ((!opto1Error) && (!powerWhileSwitchedOffError)) {
        FET1BlinkOff();
        FET1Off();
      }
    }
  });
  node.onDisconnect([]() {
    Log.println("Disconnected");
    FET1BlinkOn(BLINK_NOT_CONNECTED);
    machinestate = NOCONN;
  });
  node.onError([](acnode_error_t err) {
    Log.printf("Error %d\n", err);
    machinestate = NOTACTIVE;
  });

 
  currentSensor.setOnLimit(CURRENT_THRESHOLD);
  currentSensor.onCurrentOn([]() {
    Serial.println("CurrentSensor = on (current detected > 4A (Irms)!)\r");
    switchPowerOff = false;
    if (machinestate < POWERED) {
      powerWhileSwitchedOffError = true;
      FET1BlinkOn(BLINK_ERROR);
      Log.println("Very strange - current observed while we are switched 'off'. Should not happen.");
    } else {
      if (machinestate != ACTIVE) {
        machinestate = ACTIVE;
        Log.println("Motor bandsaw started");
      };
    };
  });

  currentSensor.onCurrentOff([]() {
    Serial.println("CurrentSensor = off (current detected < 4A (Irms)!\r");
    // We let the auto-power off on timeout do its work.
    if (machinestate > POWERED) {
      machinestate = POWERED;
      Log.println("Motor stopped");
    } else {
        if (machinestate < POWERED) {
          if (powerWhileSwitchedOffError) {
            powerWhileSwitchedOffError = false;
            FET1BlinkOff();            
          };
        }
    }
  });

  node.onApproval([](const char * machine) {
  if (!opto1Error && !powerWhileSwitchedOffError) {
      Debug.print("Got approve for using the bandzaag: \n\r");

      getCurrentNTPDateTime();

      Log.printf("%s => Approve received to use bandzaag\n\r", ntpCurrentDateTimeStr);    
      
      Debug.println(machine);
      if ((machinestate == NOTACTIVE) || (machinestate == CHECKINGCARD)) {
        approvedCards++;
        machinestate = APPROVED;
        Serial.print("User is approved!\n\r");
      }
    }
  });

  node.onDenied([](const char * machine) {
    if (!opto1Error && !powerWhileSwitchedOffError) {
      FET1BlinkOn(BLINK_ERROR);
      relay1Off();
      
      Debug.println("Got denied");
      Serial.print("User is denied!\n\r");

      getCurrentNTPDateTime();

      Log.printf("%s => Deny received for using the bandzaag\n\r", ntpCurrentDateTimeStr);    

      machinestate = REJECTED;
    }
  });

  // For test:  
  // node.set_report_period(10 * 1000);
  node.set_report_period(REPORT_PERIOD);
  node.onReport([](JsonObject  & report) {
    report["state"] = state[machinestate].label;

#ifdef OTA_PASSWD
    report["ota"] = true;
#else
    report["ota"] = false;
#endif
    snprintf(reportStr, sizeof(reportStr), "%lu", approvedCards);
    report["approved cards"] = reportStr;
    snprintf(reportStr, sizeof(reportStr), "%lu", rejectedCards);
    report["rejected cards"] = reportStr;

    theLocalIPAddress = node.localIP();
    report["IP_address"] = theLocalIPAddress.toString();
    report["Last_Reboot"] = ntpBootDateTimeStr;
    report["Software_Version"] = SOFTWARE_VERSION;
  });

  reader.onSwipe([](const char * tag) -> ACBase::cmd_result_t {
    // avoid swithing messing with the swipe process
    if (opto1Error || powerWhileSwitchedOffError) {
      if (opto1Error) {
        Debug.printf("Ignoring a normal swipe - error: bandzaag is already powered! Must be manualy switched off first!");
      } else {
        if (powerWhileSwitchedOffError) {
          Debug.printf("Ignoring a normal swipe - error: power detected while relais is not switched on yet");
        }
      }
      checkNFCReaderAvailable(true);
      return ACBase::CMD_CLAIMED;
    } else {
      if ((machinestate == ACTIVE) || (machinestate == POWERED) || (machinestate == APPROVED)) {
        Debug.printf("Ignoring a normal swipe - bandzaag is already active, or powered, or RFID card is already approved.");
        checkNFCReaderAvailable(true);
        return ACBase::CMD_CLAIMED;
      }
    }

    // We'r declining so that the core library handle sending
    // an approval request, keep state, and so on.
    //
    Debug.printf("Detected a normal swipe.\n");
    checkNFCReaderAvailable(true);
    FET1BlinkOn(BLINK_CHECKING_RFIDCARD);
    machinestate = CHECKINGCARD;
  //  buzz = CHECK;
    return ACBase::CMD_DECLINE;
  });


  // This reports things such as FW version of the card; which can 'wedge' it. So we
  // disable it unless we absolutely positively need that information.
  //
  reader.set_debug(false);
  node.addHandler(&reader);
 
#ifdef OTA_PASSWD
  node.addHandler(&ota);
#endif

  Log.addPrintStream(std::make_shared<MqttLogStream>(mqttlogStream));

  auto t = std::make_shared<TelnetSerialStream>(telnetSerialStream);
  Log.addPrintStream(t);
  Debug.addPrintStream(t);

  // node.set_debug(true);
  // node.set_debugAlive(true);

// if Olimex ESP32-PoE board is used
#ifdef ESP32_PoE  
  node.begin(BOARD_OLIMEX);
#endif

  initNTP();

// if default, board (POESP, board Aart) is used
#ifndef ESP32_PoE
  node.begin();
#endif
  Log.println("Booted: " __FILE__ " " __DATE__ " " __TIME__ );
  Log.println(ntpBootDateTimeStr);

  resetNFCReader();
}

unsigned long now;
unsigned long lastCheckSwitch1 = 0;
bool currentResetButtonPressed = false;
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
void loop() {
  node.loop();

  FET1BlinkLoop();

  now = millis();

  optocoupler_loop();

  currentSensor.loop();

  if ((now - NTPUpdatedTime) > NTP_UPDATE_WINDOW) {
    ntp.update();
    NTPUpdatedTime = now;
  }

  if (USE_NFC_RFID_CARD) {
    if ((now - lastCheckNFCReaderTime) > CHECK_NFC_READER_AVAILABLE_TIME_WINDOW) {
      lastCheckNFCReaderTime = now;
      Serial.print("Check Reader Available\n\r");
      checkNFCReaderAvailable(false);
    }
  }

  if (laststate != machinestate) {
    Debug.printf("Changed from state <%s> to state <%s>\n",
                 state[laststate].label, state[machinestate].label);

    state[laststate].timeInState += (millis() - laststatechange) / 1000;
    laststate = machinestate;
    laststatechange = millis();
    return;
  }

  if (state[machinestate].maxTimeInMilliSeconds != NEVER &&
      ((millis() - laststatechange) > state[machinestate].maxTimeInMilliSeconds))
  {
    state[machinestate].timeoutTransitions++;

    laststate = machinestate;
    machinestate = state[machinestate].failStateOnTimeout;

    Log.printf("Time-out; transition from <%s> to <%s>\n",
               state[laststate].label, state[machinestate].label);
    return;
  };

  if (state[machinestate].autoReportCycle && \
      (millis() - laststatechange) > state[machinestate].autoReportCycle && \
      (millis() - lastReport) > state[machinestate].autoReportCycle)
  {
    Log.printf("State: %s now for %lu seconds", state[laststate].label, (millis() - laststatechange) / 1000);
    lastReport = millis();
  };

  switch (machinestate) {
    case REBOOT:
      node.delayedReboot();
      break;

    case NOTACTIVE:
    case CHECKINGCARD:
      break;
    case CLEARSTATUS:
      if (!opto1Error && !powerWhileSwitchedOffError) {
        relay1Off();
        FET1BlinkOff();
        machinestate = NOTACTIVE;
      }
      break;
    case APPROVED:
      if (!opto1Error && !powerWhileSwitchedOffError) {
        relay1On();
        FET1BlinkOff();
        FET1On();
        powerWhileSwitchedOffError = false;
        machinestate = POWERED;
      } else {
        machinestate = NOTACTIVE;
      }
      break;
    case REJECTCARD:
      if (!opto1Error && !powerWhileSwitchedOffError) {
        FET1BlinkOn(BLINK_ERROR);
        relay1Off();
      
        Debug.println("User not approved in time");
        Serial.print("User not approved in time, user is rejected!\n\r");

        getCurrentNTPDateTime();
        Log.printf("%s => Approve not received in time for using the bandzaag\n\r", ntpCurrentDateTimeStr);    

        machinestate = REJECTED;
      } else {
        machinestate = NOTACTIVE;
      }
      break;
    case REJECTED:
      break;
    case POWERED:
      if ((millis() - laststatechange) > MAX_IDLE_TIME) {
        Log.printf("Machine idle for too long - switching off.\n");
        machinestate = CLEARSTATUS;
      }
      break;
    case ACTIVE:
      break;
    case BOOTING:
    case OUTOFORDER:
    case TRANSIENTERROR:
    case NOCONN:
      break;
  };
}

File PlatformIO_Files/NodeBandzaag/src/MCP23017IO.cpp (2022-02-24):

/*
      Copyright 2021      Hans Beerman <hans.beerman@xs4all.nl>
                          Stichting Makerspace Leiden, the Netherlands.

   Licensed under the Apache License, Version 2.0 (the "License");
   you may not use this file except in compliance with the License.
   You may obtain a copy of the License at

       http://www.apache.org/licenses/LICENSE-2.0

   Unless required by applicable law or agreed to in writing, software
   distributed under the License is distributed on an "AS IS" BASIS,
   WITHOUT WARRANTIES OR CONDITIONS OF ANY KIND, either express or implied.
   See the License for the specific language governing permissions and
   limitations under the License.
*/

#include <Wire.h>
#include "MCP23017IO.h"
#include <Arduino.h>
//#include "RFID.h"

Adafruit_MCP23X17 mcp;

#define INPUT_CHANGE_WINDOW     500 // in ms = time input changes are not taking into account
#define FET1_OUTPUT             11
#define FET2_OUTPUT             12
#define RELAY1_OUTPUT           8
#define RELAY2_OUTPUT           9
#define RELAY3_OUTPUT           10
#define SWITCH1_INPUT           0
#define SWITCH2_INPUT           1
#define SWITCH3_INPUT           2

bool relay1IsOn = false;
bool FET1IsOn = false;

unsigned long FET1BlinkTime;
unsigned long FET1BlinkStartTime;
bool FET1BlinkIsOn = false;
bool FET1BlinkFETIsOn = false;
bool setupReady = false;

void setup_MCP23017() {
    Wire.begin(RFID_SDA_PIN, RFID_SCL_PIN, RFID_I2C_FREQ);
    mcp.begin_I2C(MCP23XXX_ADDR, &Wire);
    mcp.pinMode(RELAY1_OUTPUT, OUTPUT);
    mcp.digitalWrite(RELAY1_OUTPUT, 0);
    mcp.pinMode(FET1_OUTPUT, OUTPUT);
    mcp.digitalWrite(FET1_OUTPUT, 0);
    setupReady = true;
}

void relay1On() {
    if (!setupReady) {
        setup_MCP23017();
    }
    if (!relay1IsOn) {
        mcp.digitalWrite(RELAY1_OUTPUT, 1);
        relay1IsOn = true;
    }
}

void relay1Off() {
    if (!setupReady) {
        setup_MCP23017();
    }
    if (relay1IsOn) {
        mcp.digitalWrite(RELAY1_OUTPUT, 0);
        relay1IsOn = false;
    }
}

void FET1On() {
    if (!setupReady) {
        setup_MCP23017();
    }
    if (!FET1IsOn) {
        mcp.digitalWrite(FET1_OUTPUT, 1);
        FET1IsOn = true;
    }
}

void FET1Off() {
    if (!setupReady) {
        setup_MCP23017();
    }
    if (FET1IsOn) {
        mcp.digitalWrite(FET1_OUTPUT, 0);
        FET1IsOn = false;
    }
}


void FET1BlinkOn(unsigned long aBlinkTime) {
    FET1On();
    FET1BlinkFETIsOn = true;
    FET1BlinkTime = aBlinkTime;
    FET1BlinkIsOn = true;
    FET1BlinkStartTime = millis();
}

void FET1BlinkOff() {
    FET1BlinkIsOn = false;
    FET1Off();
}

void FET1BlinkLoop() {
    if (FET1BlinkIsOn) {
        unsigned long now = millis();
        if ((now - FET1BlinkStartTime) >= FET1BlinkTime) {
            if (FET1BlinkFETIsOn) {
                FET1Off();
                FET1BlinkFETIsOn = false;
            } else {
                FET1On();
                FET1BlinkFETIsOn = true;
            }
            FET1BlinkStartTime = now;
        }
    }
}

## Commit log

2021-12-08 First release of the Node bandzaag, node is not ready yet
    [NodeBandzaag-B_Cu.gbr, NodeBandzaag-B_Mask.gbr, NodeBandzaag-B_Paste.gbr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]
2021-12-14 V1.0.0.0 Updated the KiCad design and added the source code for the node
    [NodeBandzaag.sch]
2021-12-23 V1.0.1.0 Switching to machinestate NOTACTIVE from POWERED or ACTIVE if 230 V voltage on optocoupler is removed
2022-01-29 V1.0.2.0 Changed the behaviour and timing e.g. when bandsaw is switched off
    [NodeBandzaag.kicad_pcb, NodeBandzaag.kicad_sch]
2022-02-26 V1.0.5.0 Lowered CURRENT_TRESHOLD because low current was detected while bandsaw was running
    [NodeBandzaag-B_Cu.gbr, NodeBandzaag-B_Mask.gbr, NodeBandzaag-B_Paste.gbr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]
